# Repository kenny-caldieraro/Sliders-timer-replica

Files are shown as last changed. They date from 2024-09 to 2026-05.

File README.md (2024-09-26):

# Sliders Timer Replica

Welcome to the **Sliders Timer Replica** project! This project faithfully recreates the iconic "Timer" from the TV show _Sliders_, a device used for traveling between parallel universes. This replica is based on an Arduino microcontroller and includes electronic components, 3D design files, and the necessary schematics to build the casing and PCB.

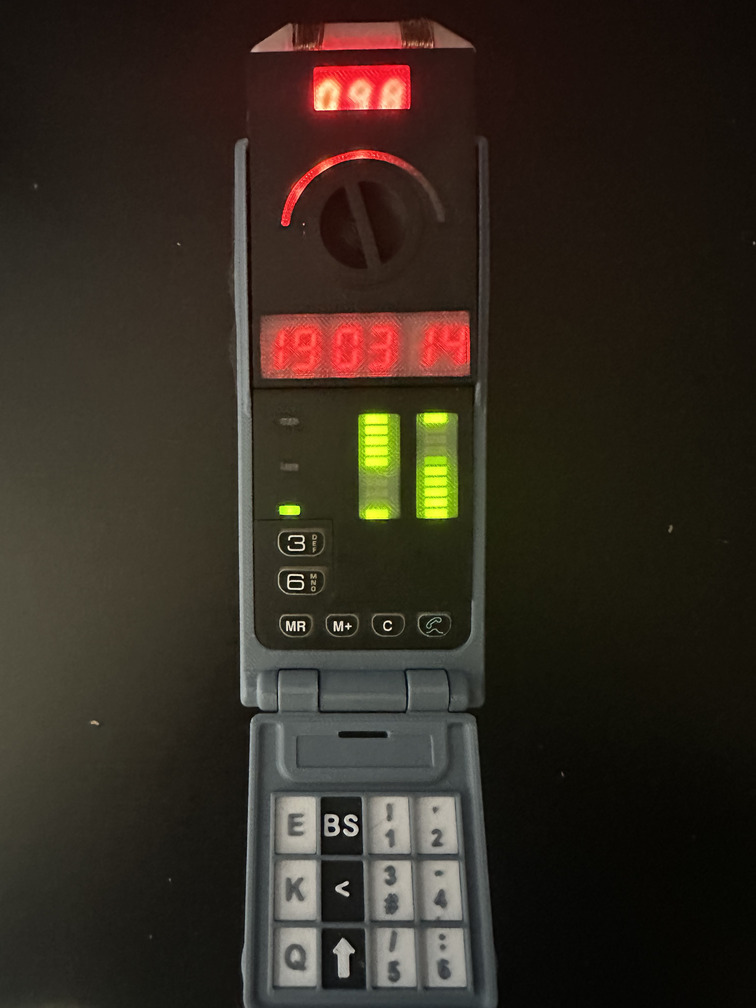
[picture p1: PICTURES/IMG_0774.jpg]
Sliders Timer Replica


## Project Content

- **Source Code**: Arduino sketch to control the Timer.
- **STL Files**: 3D models for printing the Timer casing.
- **Electronic Schematic**: Complete circuit diagrams for assembling the components.
- **Gerber Files**: Files for fabricating the PCB.
- **Photos**: Images of the completed Timer and various construction stages.

## Features

- **Visual and Functional Replica**: Design inspired by the _Sliders_ Timer, featuring an LED display to simulate the countdown.
- **Arduino Timer**: The Timer uses an Arduino microcontroller to handle the countdown and display functions.
- **3D Printable Casing**: All the necessary files to 3D print the casing are included in STL format.
- **DIY PCB**: The schematic and Gerber files allow you to build your own PCB for the Timer.
- **Easily Modifiable**: The code and schematics are provided for you to modify or improve as needed.

## Required Materials

To build this project, you will need the following:

- **Arduino Microcontroller** (e.g., Arduino Nano or similar)
- **7-segment LED display** or equivalent
- **Push buttons** for controls
- **Resistors, capacitors, etc.** (see the electronic schematic for a full list of components)
- **PCB** (Gerber files included for fabrication)
- **3D printed casing** (STL files provided)

### Component List

You can find the full list of required components in the [component list](./PARTS/ORIGINAL%20TIMERS%20PARTS.pdf) provided in this repository. This includes all resistors, capacitors, connectors, and other electronic parts required for the assembly.

## Installation Instructions

1. **Download the repository**:
   Clone this repository to your local machine:

   ```bash
   git clone https://github.com/kenny-caldieraro/Sliders-timer-replica.git

   ```

2. **3D Printing**:
   Print the casing parts using the provided STL files. Make sure you have a 3D printer and the appropriate filament.

3. **PCB Fabrication**:
   Use the Gerber files to order or fabricate the PCB.

4. **Electronic Assembly**:
   Assemble the electronic components as shown in the provided schematic and solder them onto the PCB.

5. **Upload the Code**:
   Upload the Arduino code to your microcontroller using the Arduino IDE:

   ```bash
   arduino-cli compile --upload
   ```

6. **Final Assembly**:
   Mount everything inside the 3D-printed casing and connect the components according to the diagrams.

## If you like it

[Support me on Buy Me a Coffee](https://buymeacoffee.com/kenny.caldieraro)

## Contributing

Contributions are welcome! If you'd like to improve this project, feel free to fork the repository and submit a pull request. Whether it's adding features, optimizing the code, or improving documentation, all help is appreciated.

## License

Sliders Timer Replica © 2021 by Kenny Caldieraro is licensed under CC BY-NC-SA 4.0 - see the LICENSE file for details.

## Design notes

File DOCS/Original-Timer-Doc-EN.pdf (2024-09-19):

Timer User Manual

Introduction

This device is an electronic apparatus based on Arduino that combines several functionalities such as display on 7-segment displays, light animations with NeoPixel LEDs, sound playback via a DFPlayer Mini MP3 module, and user interaction through multiple buttons.

Main Features

- Time Display: Shows days, hours, minutes, and seconds on 7-segment displays.
- LED Animations: Multiple integrated visual animations, including special effect sequences.
- Sound Management: Playback of sounds and tones via an integrated speaker.
- Battery Level Measurement: Displays the remaining battery percentage.
- Display of Remaining Time: Shows the remaining time in normal mode.
- Special Modes:
- Sleep and Wake Mode
- Test Mode
- Burnout Mode
- 29 Years Mode
- Parameter Control: Setting the timer (seconds, minutes, hours, days) via the buttons.

Description of Buttons

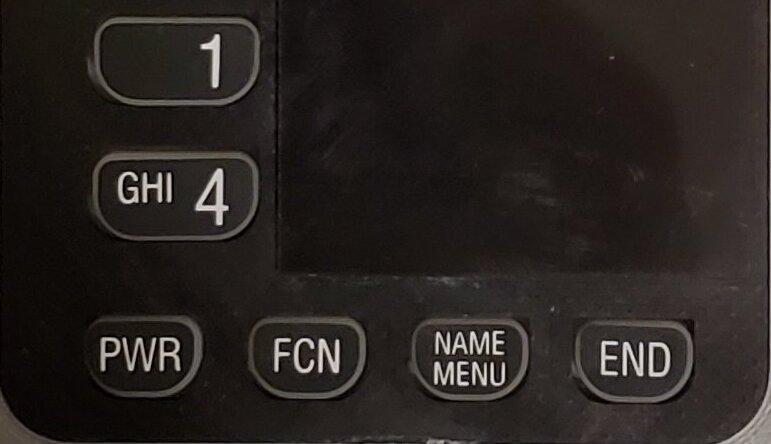
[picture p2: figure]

Button 1 (VORTEX) (BP_VORTEX - connected to A5)

- Press: Activates Burnout mode (if the timer is in normal mode), launching a special sequence of animations and sounds. No more control—the time is calculated randomly using a seed generated by the power adjustment potentiometer.

Button 4 (Sleep) (BP1 - connected to A4)

- Short Press: Puts the device into sleep mode. The displays and LEDs are turned off, and the buzzer is deactivated.
- Long Press: Wakes the device from sleep mode. The displays and LEDs are turned back on, and the buzzer is reactivated.
- Double Click: Directly accesses the timer setting menu.

Button PWR (Power) (BP2 - connected to A3)

- Short Press: Navigates to the next menu to set the timer (when the timer is not counting down).
- Long Press: Restarts the device.
- Double Click: Activates the timer with the current parameters.

Button FCN (DOWN) (BP_DOWN - connected to A2)

- In Setting Menus: Decreases the value of the current parameter (seconds, minutes, hours, days).
- Simultaneous Press with BP_UP: Activates test mode.
- During Timer Execution: Displays the battery level.

Button NAME MENU (UP) (BP_UP - connected to A1)

- In Setting Menus: Increases the value of the current parameter (seconds, minutes, hours, days).
- Simultaneous Press with BP_DOWN: Activates test mode.
- During Timer Execution: Displays the remaining time (only in normal mode).

Button END (START STOP) (BP_START - connected to A0)

- Simple Press: Starts the countdown after settings (SLIDE on the screen) in normal mode.
- During Timer Execution:
- Press: Activates or deactivates the buzzer.

Using the Device

Starting Up

- To turn on the device, double-click the Power button.

Sleep Mode

- To put the device into sleep mode, perform a short press on the Sleep button.
- The displays and LEDs turn off, and the buzzer is deactivated to save energy.

Exiting Sleep Mode

- To exit sleep mode, double-click the Sleep button.
- Note: Sleep mode does not stop the timer operation; it continues counting.

Setting the Timer

!!! IMPORTANT !!!

- The timer must be in a "waiting" state, indicated by the Arduino's status LED 13 blinking. By default, the timer is in this state at startup, but it may not always be the case. Simply click once on the Start/Stop button to set it.

Accessing the Setting Menu

- Press the POWER button to navigate through the timer setting menus.
- Each click advances you to the next menu.
- When the message “Slide” is displayed, you can click the START/STOP button to start the sequence. If an error message appears, the setting is incorrect.

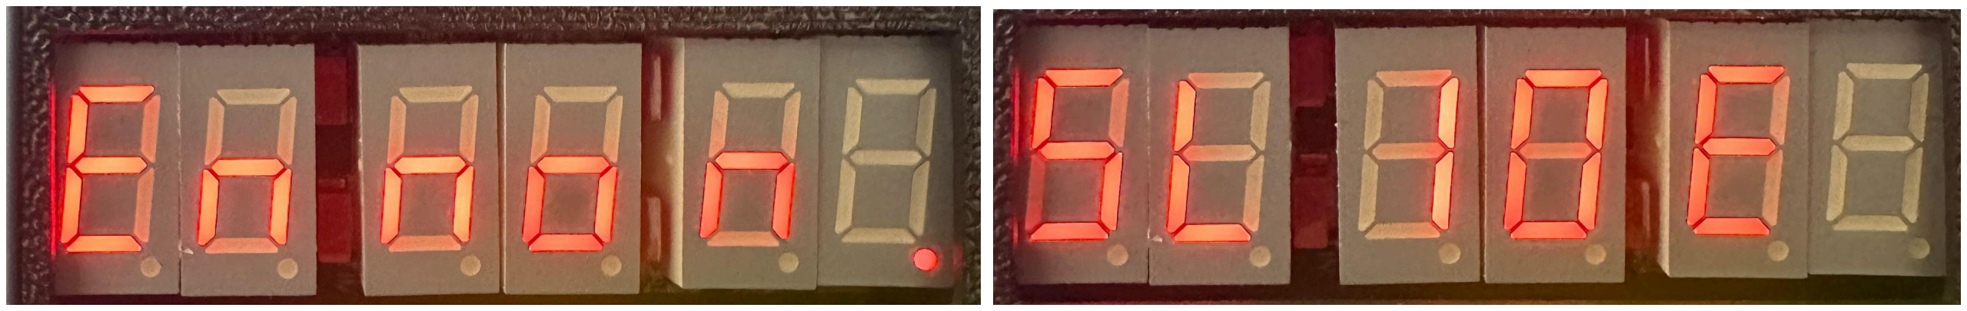
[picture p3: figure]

Selecting Parameters

- Menu 1: Setting seconds.
- Menu 2: Setting minutes.
- Menu 3: Setting hours.
- Menu 4: Setting days.
- Menu 5: Confirmation of parameters.
- Menu 6: Slide or Error message. If Slide, click the Start/Stop button to launch the sequence.

Adjusting Values

- Use the UP button to increase the value.
- Use the DOWN button to decrease the value.

Starting the Timer

- After setting the parameters, press the START/STOP button to launch the timer.

Timer Execution

While the timer is running:

- The device displays the elapsed time.
- Specific LED animations and sounds are played depending on the remaining time.
- Button Functions:
- DOWN: Displays the battery level.
- UP: Displays the remaining time.
- START/STOP (click): Activates or deactivates the buzzer.
- SLEEP (click/long press): Activates sleep mode or wakes up the timer.
- VORTEX: If clicked during the countdown, it activates the slide too early (Burnout mode), and the timer enters random mode.

Burnout Mode

- To activate Burnout mode, press the VORTEX button during timer execution.
- This mode launches a special sequence with unique animations and sounds.
- Initially, a 1 minute 30 seconds countdown is launched for demonstration. Then, depending on the position of the power potentiometer, a random time is calculated for each cycle.
- Important: In this mode, you must click the VORTEX button when there are between 0 and 2 seconds left to change the cycle; otherwise, the timer enters 29 Years Mode.
- Button Functions:
- DOWN: Displays the battery level.
- START/STOP (click): Activates or deactivates the buzzer.
- SLEEP (click/long press): Activates sleep mode or wakes up the timer.
- VORTEX: Activates the vortex when less than 2 seconds remain.

### 29 Years Mode

- You missed your slide in Burnout mode? Too bad—you are stuck here for 29 years. Hope this world suits you.

Displaying Battery Level

- At any time, you can display the battery level by pressing the DOWN button during timer execution.
- The device will display the remaining battery percentage on the 7-segment displays.

Test Mode

- To access test mode, press the UP and DOWN buttons simultaneously when the timer is in waiting mode.
- Test mode lights up all the LEDs and displays all the animations to verify the device's proper functioning.
- A continuous sound is emitted during the test.
- Test mode lasts 10 seconds, after which the device returns to the previous state.

Restarting the Device

- To restart the device, perform a long press on the POWER button.
- The device restarts, which can be useful in case of malfunction.

Visual and Sound Indications

- NeoPixel LEDs: Indicate the timer's power/generation of the random seed.
- 7-Segment Displays: Display time, animations, and special messages.
- Buzzer: Emits tones to signal specific events (startup, alerts, etc.).
- Speaker: Plays MP3s (vortex sound).

Safety and Precautions

- Ensure that the battery is correctly connected and charged to avoid any malfunction.
- Avoid pressing multiple buttons simultaneously unless otherwise indicated (as in test mode).
- Handle the device carefully to preserve sensitive electronic components.
- Do not connect the USB cable to the Arduino when the timer is powered by its battery. (Turn off the timer or disconnect the battery)

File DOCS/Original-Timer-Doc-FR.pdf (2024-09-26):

# Notice d'utilisation du minuteur

## Introduction

Cet appareil est un dispositif électronique basé sur Arduino qui combine plusieurs fonctionnalités telles que l'affichage sur afficheurs 7 segments, des animations lumineuses avec des LEDs NeoPixel, la lecture de sons via un module MP3 DFPlayer Mini, et l'interaction avec l'utilisateur grâce à plusieurs boutons.

## Caractéristiques Principales

- Affichage du temps : Affichage des jours, heures, minutes et secondes sur des afficheurs 7 segments.
- Animations LED : Plusieurs animations visuelles intégrées, y compris des séquences d'effets spéciaux.
- Gestion du son : Lecture de sons et tonalités via un haut-parleur intégré.
- Mesure du niveau de batterie : Affichage du pourcentage de la batterie restante.
- Affichage du temps restant : Affichage du temps restant en mode normal
- Modes Spéciaux :
- Mode Veille et Réveil
- Mode Test
- Mode Burnout
- Mode 29 years
- Contrôle des paramètres : Réglage du minuteur (secondes, minutes, heures, jours) via les boutons.

## Description des Boutons


Bouton 1 (VORTEX) (BP_VORTEX - connecté sur A5)

- Appui : Active le mode Burnout (si le minuteur est en mode normal), lançant une séquence spéciale d'animations et de sons. Plus de contrôle, le temps est calculé de manière aléatoire, en utilisant une graine générée par le potentiomètre de réglage de la puissance.

Bouton 4 (Sleep) (BP1 - connecté sur A4)

- Appui Court : Met l'appareil en mode veille. Les affichages et les LEDs sont éteints, et le buzzer est désactivé.
- Appui Long : Réveille l'appareil du mode veille. Les affichages et les LEDs sont rallumés, et le buzzer est réactivé.
- Double Clic : Accède directement au menu de réglage du minuteur.

Bouton PWR (Power) (BP2 - connecté sur A3)

- Appui Court : Navigue vers le menu suivant pour régler le minuteur. (Quand le minuteur n’est pas en train de décompter)
- Appui Long : Redémarre l'appareil.
- Double Clic : Active le minuteur avec les paramètres actuels.

Bouton FCN (DOWN) (BP_DOWN - connecté sur A2)

- Dans les menus de réglage : Diminue la valeur du paramètre en cours (secondes, minutes, heures, jours).
- Appui simultané avec BP_UP : Active le mode test.
- Pendant l'exécution du minuteur : Affiche le niveau de batterie.

Bouton NAME MENU (UP) (BP_UP - connecté sur A1)

- Dans les menus de réglage : Augmente la valeur du paramètre en cours (secondes, minutes, heures, jours).
- Appui simultané avec BP_DOWN : Active le mode test.
- Pendant l'exécution du minuteur : Affiche le temps restant (uniquement en mode normal).

Bouton END (START STOP) (BP_START - connecté sur A0)

- Appui simple : Démarre le compte à rebours après les réglages (SLIDE à l’écran) en mode normal.
- Pendant l'exécution du minuteur :
- Appui : Active ou désactive le buzzer.

## Utilisation de l'Appareil

Démarrage

- Pour allumer l'appareil, double-cliquez sur le bouton Power.

Mise en veille

- Pour mettre l'appareil en veille, effectuez un appui court sur le bouton Sleep.
- Les affichages et les LEDs s'éteignent, et le buzzer est désactivé pour économiser de l'énergie.

Sorti de veille

- Pour sortir de la veille double-cliquez sur le bouton Sleep.

Info : La mise en veille ne stoppe pas le fonctionnement du minuteur, il continue à compter.

Réglage du Minuteur
!!! IMPORTANT !!!

Le minuteur doit être en état “attente”, LED de statut 13 de l’Arduino qui clignote. Par défaut, le minuteur est dans cet état au démarrage, mais il peut arriver que ce ne soit pas le cas. Il suffit de cliquer une fois sur le bouton start/stop.

1. Accéder au Menu de Réglage :
- Appuyez sur le bouton POWER pour naviguer dans les menus de réglage du minuteur.
- Chaque clic vous fait changer de menu.
- Quand le message “Slide” est affiché, vous pouvez cliquer sur le bouton START/STOP pour démarrer la séquence. Si le message d'erreur s’affiche, le réglage n’est pas bon.

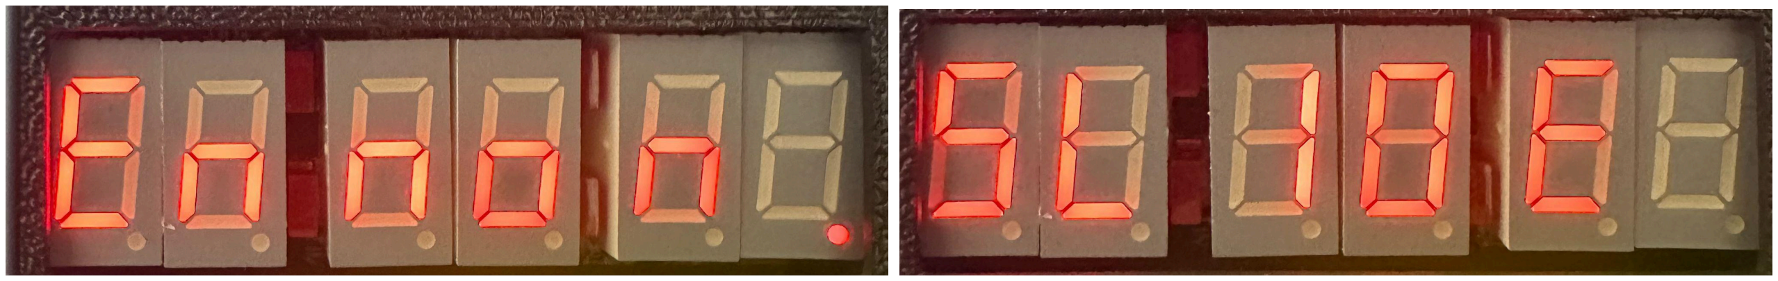
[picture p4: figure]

2. Sélection des Paramètres :
- Menu 1 : Réglage des secondes.
- Menu 2 : Réglage des minutes.
- Menu 3 : Réglage des heures.
- Menu 4 : Réglage des jours.
- Menu 5 : Confirmation des paramètres.

- Menu 6 : Message Slide ou Error => si Slide cliquez sur le bouton Start/Stop lance la séquence.
3. Ajustement des Valeurs :
- Utilisez le bouton UP pour augmenter la valeur.
- Utilisez le bouton DOWN pour diminuer la valeur.
4. Lancement du Minuteur :
- Après avoir réglé les paramètres, appuyez sur le bouton START/STOP pour lancer le minuteur.

Exécution du Minuteur

- Pendant que le minuteur est en cours :
- L'appareil affiche le temps passé.
- Des animations LED et des sons spécifiques sont joués en fonction du temps restant.
- Les boutons ont les fonctions suivantes :
■ DOWN : Affiche le niveau de batterie.
■ UP : Affiche le temps restant.
■ START/STOP (clic) : Active ou désactive le buzzer.
■ SLEEP : (clic / appui long) Active la veille ou sort de veille le minuteur. ■ VORTEX : Si on clique pendant le compte à rebours, cela active la glisse trop tôt (mode Burnout), le minuteur entre alors en mode aléatoire.

Mode Burnout

- Pour activer le mode Burnout, appuyez sur le bouton VORTEX pendant l'exécution du minuteur.
- Ce mode lance une séquence spéciale avec des animations et des sons uniques.
- Dans un premier temps, un compte à rebours de 1m30 est lancé pour la démonstration, puis, en fonction de la position du potentiomètre de puissance, un temps aléatoire est calculé à chaque cycle.
- Dans ce mode, il faut impérativement cliquer sur le bouton VORTEX quand il reste entre 0 et 2 secondes pour changer de cycle, sinon le minuteur entre en mode 29y.
- Les boutons ont les fonctions suivantes :
- DOWN : Affiche le niveau de batterie.
- START/STOP (clic) : Active ou désactive le buzzer.
- SLEEP : (clic / appui long) Active la veille ou sort de veille le minuteur.
- VORTEX :Active le vortex quand il reste moins de 2 secondes.

Mode 29 ans

- Vous avez raté votre glisse dans le mode Burnout ? Dommage, vous êtes bloqué ici pendant 29 ans. J'espère que ce monde vous convient.

Affichage du Niveau de Batterie

- À tout moment, vous pouvez afficher le niveau de batterie en appuyant sur le bouton DOWN pendant l'exécution du minuteur.
- L'appareil affichera le pourcentage de batterie restante sur les afficheurs 7 segments.

Mode Test

- Pour accéder au mode test, appuyez simultanément sur les boutons UP et DOWN quand le minuteur est en attente.
- Le mode test allume toutes les LEDs et affiche toutes les animations pour vérifier le bon fonctionnement de l'appareil.
- Un son continu est émis pendant le test.
- Le mode test dure 10 secondes, après quoi l'appareil revient à l'état précédent.

Redémarrage de l'Appareil

- Pour redémarrer l'appareil, effectuez un appui long sur le bouton POWER.
- L'appareil redémarre, ce qui peut être utile en cas de dysfonctionnement.

## Indications Visuelles et Sonores

- LEDs NeoPixel : Indiquent la puissance du minuteur / génération de la graine aléatoire.
- afficheurs 7 segments : Affichent le temps, les animations, et les messages spéciaux.
- Buzzer : Émet des tonalités pour signaler des événements spécifiques (démarrage, alertes, etc.).
- Haut parleur : Émet des MP3 (bruit du vortex).

## Sécurité et Précautions

- Assurez-vous que la batterie est correctement connectée et chargée pour éviter tout dysfonctionnement.
- Évitez d'appuyer sur plusieurs boutons simultanément, sauf indication contraire (comme pour le mode test).
- Manipulez l'appareil avec soin pour préserver les composants électroniques sensibles.
- Ne surtout pas brancher le câble USB à l’Arduino quand le minuteur est alimenté par sa batterie. (Éteindre le minuteur ou déconnecter la batterie)

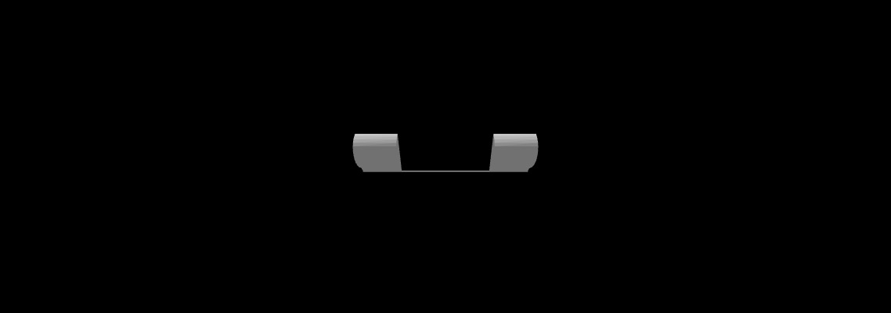
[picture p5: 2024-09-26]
STL/IMAGES/Flip_panels_nubs.STL.jpg

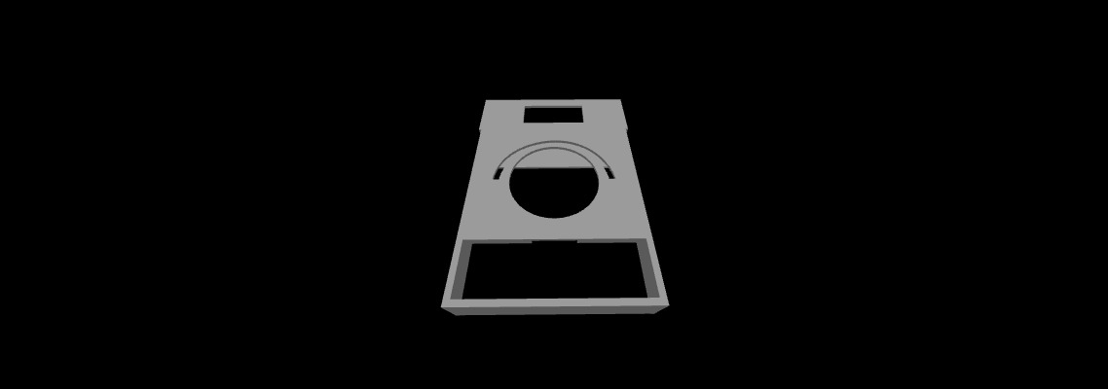
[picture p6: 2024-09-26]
STL/IMAGES/Top_face v1.jpg

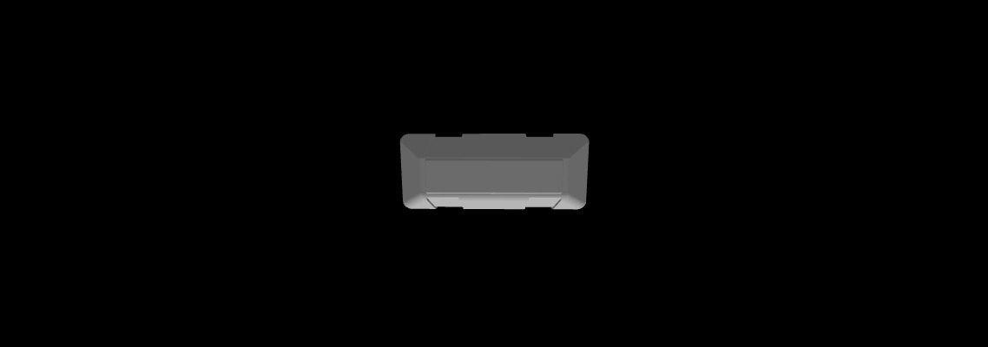
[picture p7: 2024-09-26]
STL/IMAGES/Crystal v3.jpg

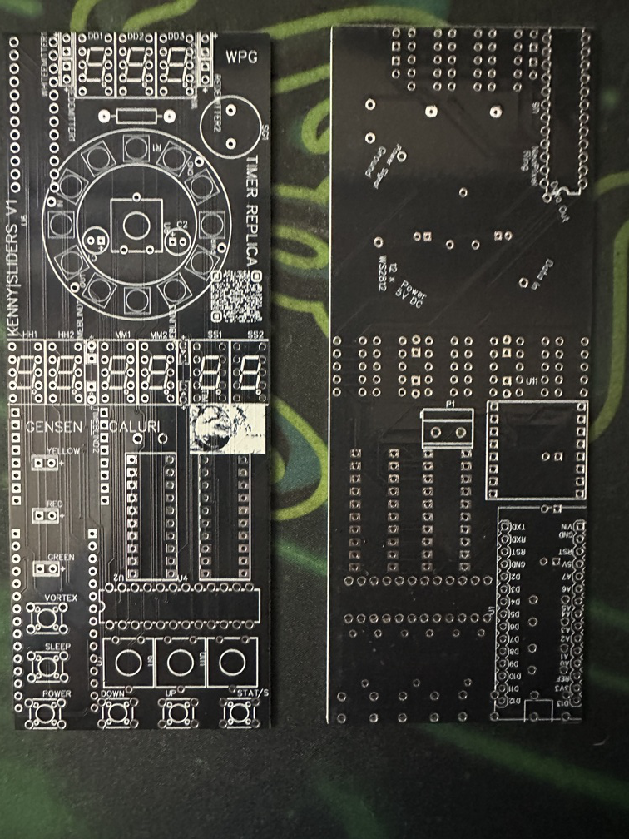
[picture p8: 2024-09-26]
PICTURES/PCB.jpeg

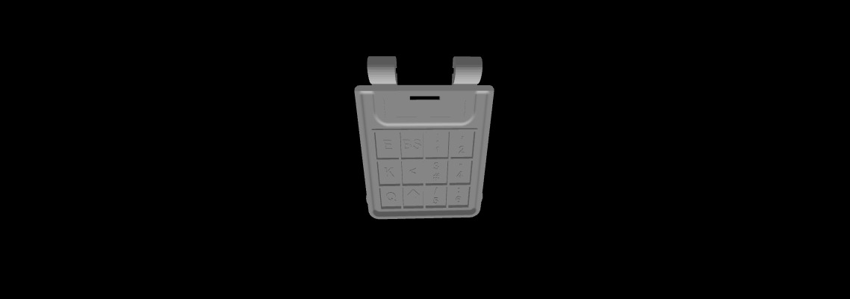
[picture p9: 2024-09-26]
STL/IMAGES/Flip_panel v7.jpg

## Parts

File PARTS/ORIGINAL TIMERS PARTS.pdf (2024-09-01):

Quantities | Name | Ref
2 | Led controller | MAX7219ENG+
6 | Button | OMRON B3F-1022
6 | 7 Segments HHMMSS | KINGBRIGHT SC36-11EWA
3 | 7 Segments DDD | BROADCOM HDSP-7513
2 | Bargraphe | KINGBRIGHT DC-10GWA
1 | Buzzer | KINGSTATE KXG1205C
4 | Blink LED | KINGBRIGHT L-144IDT
1 | Red LED | KINGBRIGHT L-113IDT
1 | Green LED | KINGBRIGHT L-103GDT
1 | Yellow LED | KINGBRIGHT L-113YDT
1 | Resistor | MCRE000037 1K 125mW
1 | Resistor | MCRE000067 330k 125mW
2 | Condensator | MCNP63V474M5X11 63v 0.47
4 | Potentiometer | 3386F-1-103TLF 10K
2 | White LED Emitter | PSG91880
2 | Red LED Emitter | 703-0100
1 | 12 LEDS | NEO Pixel led ring
1 | Arduino NANO | Arduino NANO
1 | MP3 SOUND | 2 pièces Module de Lecteur MP3 Open Source Mini capteur de Lecteur MP3 avec boîtier métallique Haut - Parleur Rond 2W 8ohm (Module 2 pièces et Haut - Parleur 4 pièces) Compatible arduino
1 | Alimentation board | Aideepen 6pcs TC4056 Type-C USB-C Input Interface USB 5V 1A 18650 LiIon Lithium Charging Board Charger Module with Dual Protection Functions (en Anglais)
1 | Battery 1s | EEMB 3.7V Lipo Battery 1800mAh Rechargeable Lithium Polymer ION Battery Pack Li Polymer Battery 3.7v Packs (1 Count, 953450
1 | Connectors | LinsyRC 10 Paires Adaptateur Connecteur Mâle et Femelle 2-Broches JST 1S 2.0 Pitch Câble pour Batterie 1S Lipo Drone de Charge Syma X5C X5SW SNAPTAIN S5C

Link
https://fr.farnell.com/analog-devices/max7219eng/driver-afficheur-led-40-a-85-c/dp/2519194

https://fr.farnell.com/omron/b3f-1022/commutateur-6x6-spno-5mm-plunger/dp/1829495

https://fr.farnell.com/kingbright/sc36-11ewa/afficheur-led-0-36-rouge-cathode/dp/2314224

https://fr.farnell.com/broadcom-limited/hdsp-7513/afficheur-a-leds-7-62mm-he-rouge/dp/1003281

https://fr.farnell.com/kingbright/dc-10gwa/bargraphe-reseau-de-10-segments/dp/2290324

https://fr.farnell.com/kingstate/kxg1205c/buzzer-magnetique-broche-85db/dp/2215080

https://fr.farnell.com/kingbright/l-144idt/led-rectangulaire-rouge-he/dp/1142602

https://fr.farnell.com/kingbright/l-113idt/led-2x5mm-superail-railouge-4mcd/dp/2314275

https://fr.farnell.com/kingbright/l-103gdt/led-2x5mm-vert-5mcd-568nm/dp/2314269

https://fr.farnell.com/kingbright/l-113ydt/led-2x5mm-jaune-4mcd-588nm/dp/2314278

https://fr.farnell.com/multicomp/mcre000037/resistance-couche-carbon-1k-0/dp/1700237

https://fr.farnell.com/multicomp/mcre000067/resistance-couche-carbon-125mw/dp/1700270

https://fr.farnell.com/multicomp/mcnp63v474m5x11/condensateur-0-47-f-63v-20/dp/1236676

https://fr.farnell.com/bourns/3386f-1-103tlf/potentiometre-trimmer-10k-10-1/dp/9354565

https://fr.farnell.com/pro-signal/psg91880/led-5mm-cool-white-water-clear/dp/4161123

https://fr.farnell.com/multicomp/703-0100/led-rouge-5mm-standard/dp/2112111

https://shorturl.at/3z6kg

https://shorturl.at/d0E4x

https://shorturl.at/T3ka4

https://www.amazon.fr/dp/B095VQRW73?ref=ppx_yo2ov_dt_b_fed_asin_title

https://www.amazon.fr/dp/B09TJDNN66?ref=ppx_yo2ov_dt_b_fed_asin_title

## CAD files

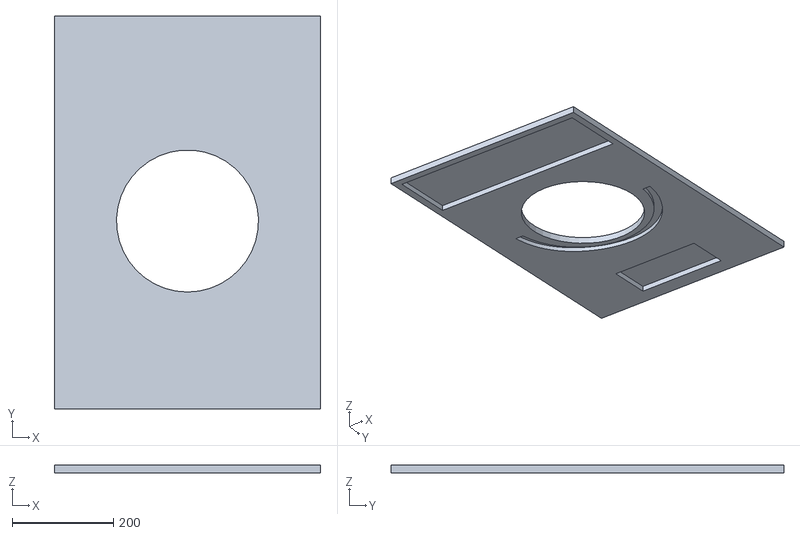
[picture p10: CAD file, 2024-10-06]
STL/FILES/Cover_Top_face v14.stl
525.0 x 775.0 x 15.0

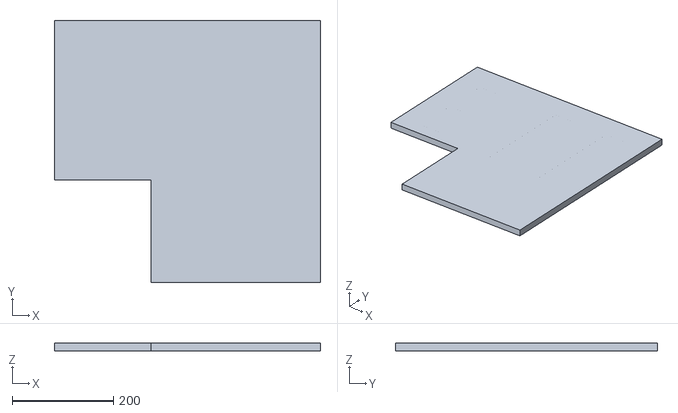
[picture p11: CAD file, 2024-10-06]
STL/FILES/Cover_Button_plate v12.stl
525.0 x 516.8 x 15.0

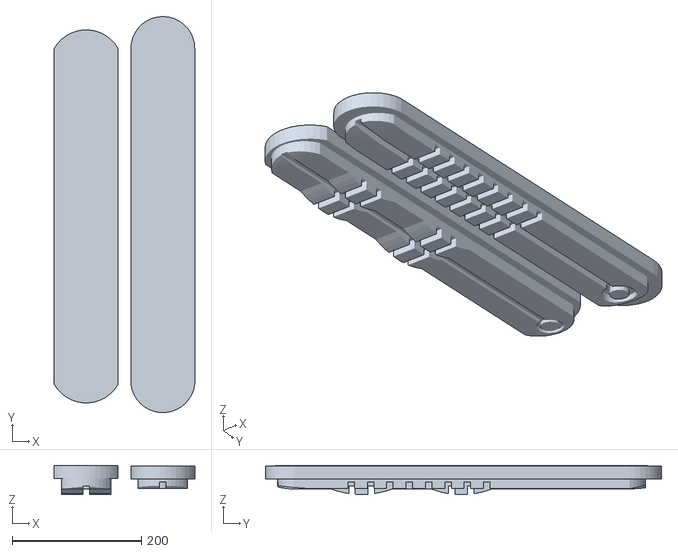
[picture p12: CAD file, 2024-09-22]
STL/FILES/Aside_parts v8.stl
217.7 x 613.1 x 45.4

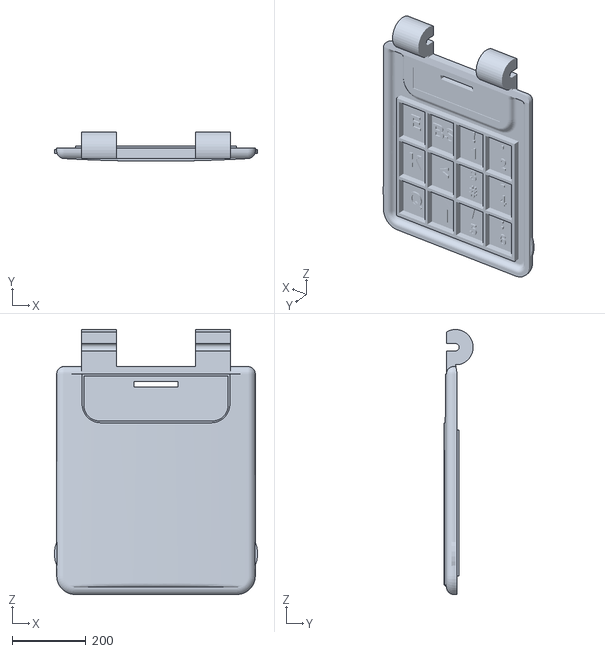
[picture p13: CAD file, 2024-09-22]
STL/FILES/Flip_panel v7.stl
549.6 x 79.5 x 717.1

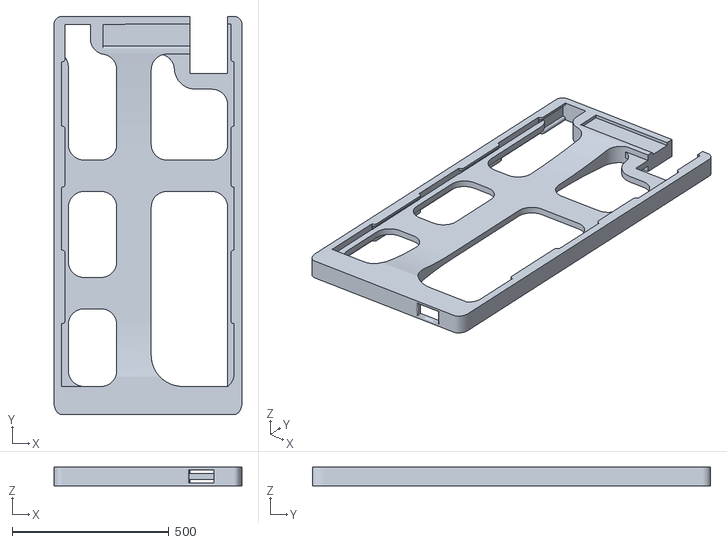
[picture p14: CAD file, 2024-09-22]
STL/FILES/Spacer_battery v9.stl
599.4 x 1270.0 x 60.0

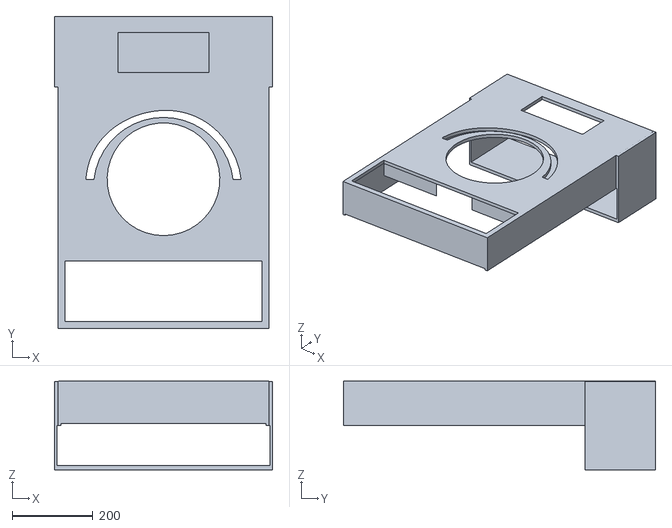
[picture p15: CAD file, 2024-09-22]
STL/FILES/Top_face v1.stl
541.8 x 775.0 x 220.2

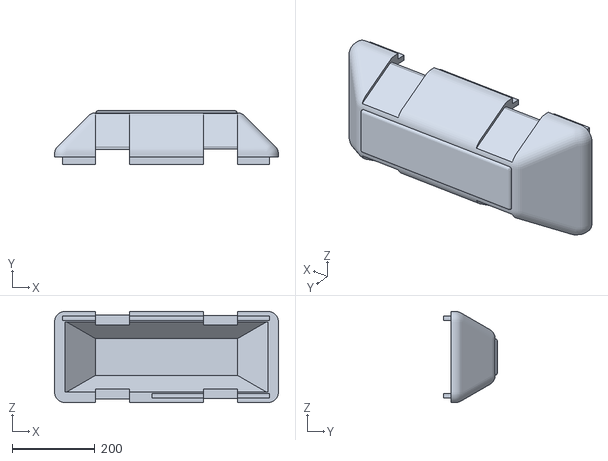
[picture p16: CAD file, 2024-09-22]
STL/FILES/Crystal v3.stl
540.8 x 129.4 x 220.2

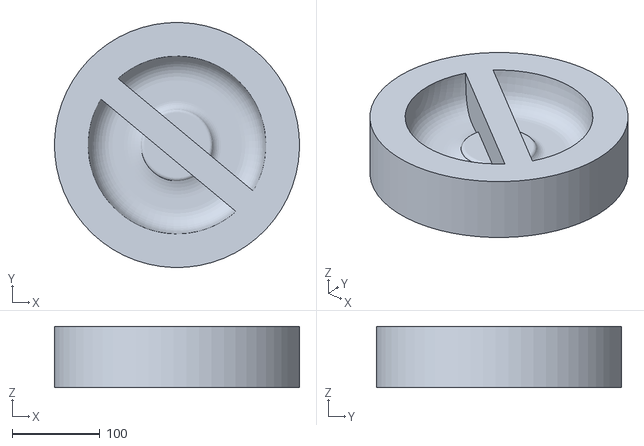
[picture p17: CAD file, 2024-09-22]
STL/FILES/Potentiometer v2.stl
279.3 x 279.3 x 69.9

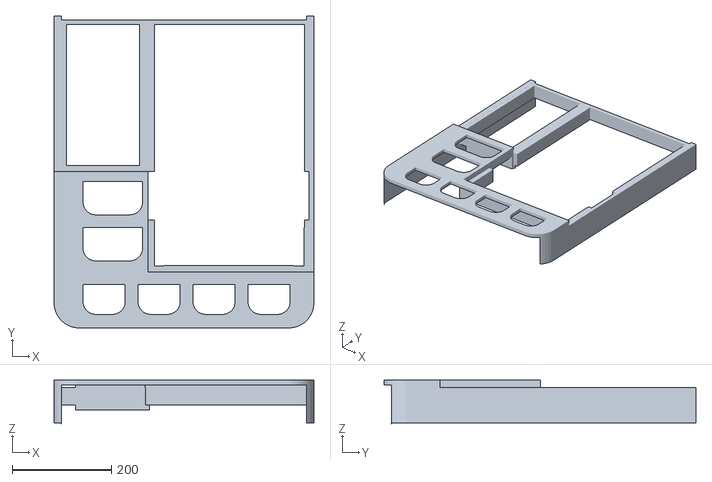
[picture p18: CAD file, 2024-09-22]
STL/FILES/Button_plate v1.stl
525.0 x 629.9 x 88.8

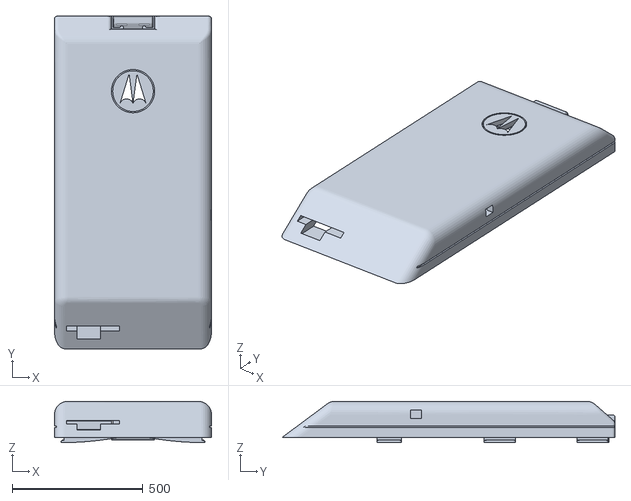
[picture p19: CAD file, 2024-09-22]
STL/FILES/Battery_box v9.stl
599.4 x 1270.5 x 157.5

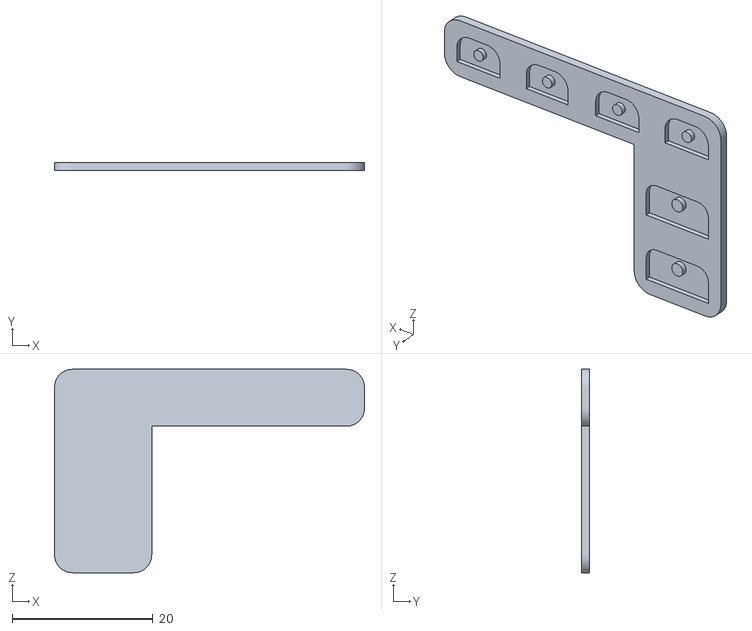
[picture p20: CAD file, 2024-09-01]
STL/FILES/Buttons_pad v2.stl
44.0 x 1.19 x 28.9

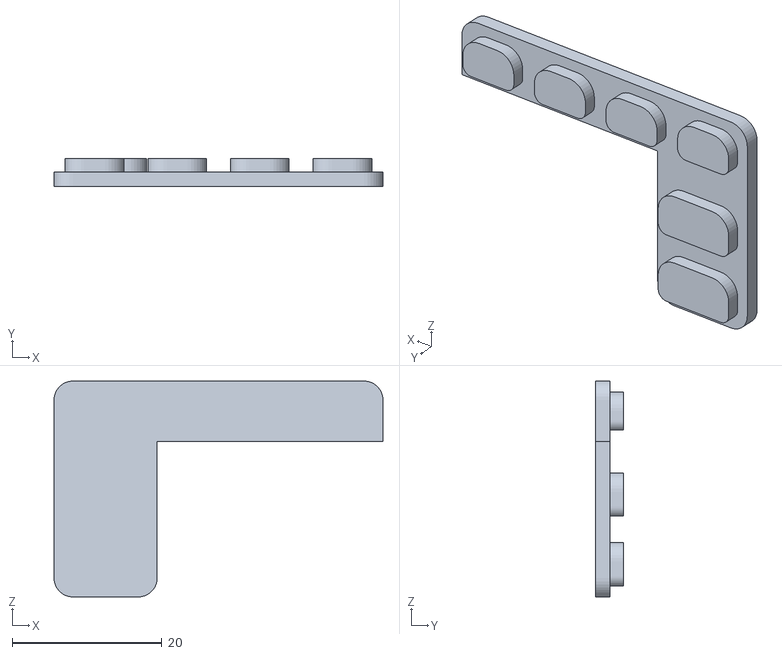
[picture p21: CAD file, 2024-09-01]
STL/FILES/Buttons.stl
44.0 x 3.68 x 28.9

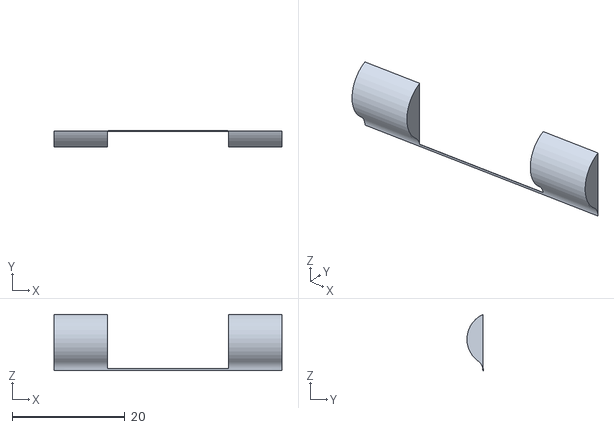
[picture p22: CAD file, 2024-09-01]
STL/FILES/Flip_panels_nubs.STL
40.4 x 2.86 x 9.95

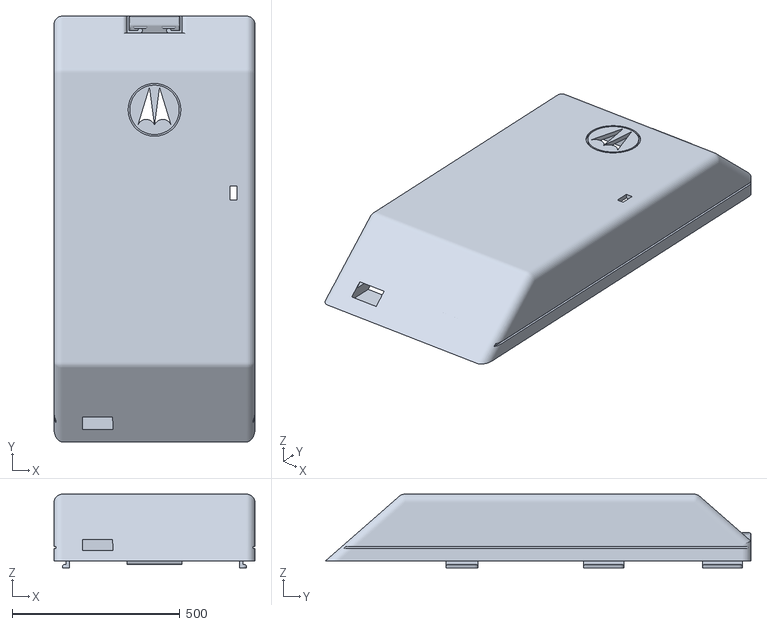
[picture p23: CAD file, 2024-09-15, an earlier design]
STL/FILES/Battery_box v1.stl
599.4 x 1270.0 x 220.0

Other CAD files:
STL/FILES/Font_face v1.stl

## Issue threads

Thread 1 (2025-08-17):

Download STLs

ondutyapp, 2025-08-17:
The downloads initially fail but when re attempted they do download but the files seem to be corrupted. Can you assist?

kenny-caldieraro, 2025-08-28:
I’m not the one managing the .zip files; they are generated directly by GitHub. The files are not corrupted—I downloaded them about 10 minutes ago to test. You still have the option to run a git clone of the repository.

Closed 2025-08-28.

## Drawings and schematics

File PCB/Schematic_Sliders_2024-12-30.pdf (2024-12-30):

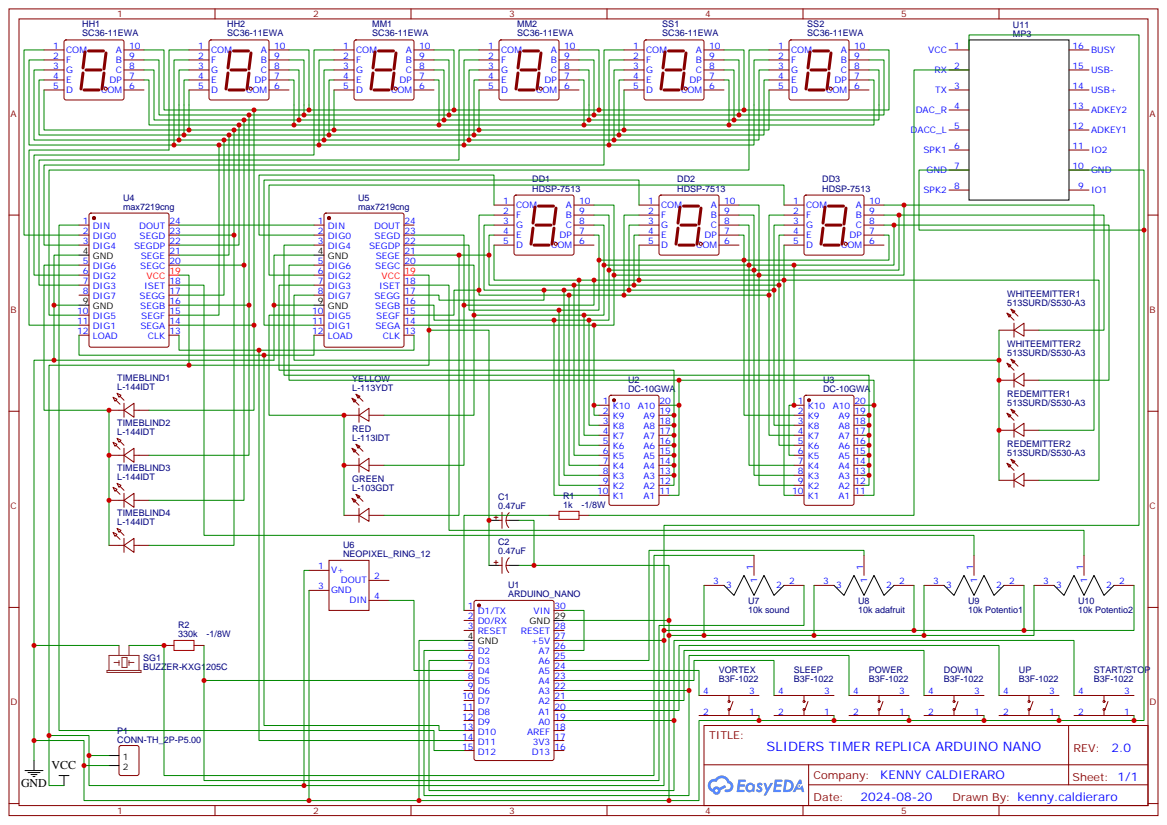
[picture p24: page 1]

Drawn By: kenny.caldieraro

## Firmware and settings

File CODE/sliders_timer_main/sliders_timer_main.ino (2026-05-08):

#include "LedControl.h"
#include "OneButton.h"
#include "Adafruit_NeoPixel.h"
#include "DFPlayer_Mini_Mp3.h"
#include <avr/wdt.h>
#include <EEPROM.h>

#define BP_START A0
#define BP_UP A1
#define BP_DOWN A2
#define ADAFRUITPIN 4
#define BP_VORTEX A5
#define BATTERYPIN A7

// --- Parametres audio / animation ---
const uint8_t  DFPLAYER_VOLUME       = 28;     // 0-30
const uint16_t START_INTRO_DELAY_MS  = 2500;   // ecrans noirs au demarrage
const uint16_t START_OUTRO_DELAY_MS  = 2500;   // attente apres l'animation pour synchro fin du clip
const uint16_t VORTEX_MP3_DURATION_MS = 8000;  // duree du 0001.mp3 (vortex)
const uint16_t COUNTDOWN_BIP_FREQ    = 3820;   // freq bip countdown (mesuree sur clip)
const uint16_t START_LOCK_TONE_FREQ  = 3000;   // freq bip de fin (3 sec / 1.5 sec)

// --- Parametres timer ---
const unsigned long SECONDS_IN_DAY    = 86400UL;
const unsigned long SECONDS_IN_HOUR   = 3600UL;
const unsigned long SECONDS_IN_MINUTE = 60UL;
const unsigned long VORTEX_RANDOM_MAX = 16756131UL;  // ~193 jours

// --- EEPROM ---
const int EEPROM_MAGIC_ADDR = 0;
const uint8_t EEPROM_MAGIC_VALUE = 0xA5;
const int EEPROM_TOTALSECTIME_SLIDE_ADDR = 1;

struct LED {
  int pinState;
  unsigned long previousMillis;
  unsigned long interval;
  int matrixIndex;
  bool isColon;
  int colIndex;
  bool isArduinoLED;
  int arduinoPin;
};

struct Bargraphe {
  const uint64_t *images;
  int length;
  int index;
  int delayTime;
};

// Format generique pour les animations 7-segments stockees en PROGMEM:
// 6 bytes matrix 0 (rows 0-5) + 5 bytes matrix 1 (rows 0-4)
// + tone optionnel (freq=0 -> pas de tone) + delay apres affichage.
struct AnimFrame {
  uint8_t r0[6];
  uint8_t r1[5];
  uint16_t tone_freq;  // 0 = pas de tone
  uint8_t tone_dur;    // duree du tone en ms
  uint8_t delay_ms;    // delay apres affichage
};

// Format pour genserSequence: pattern affiche-bip-attend-clear-attend.
struct GenserFrame {
  uint8_t r0[6];
  uint8_t r1[5];
  uint16_t hold_ms;        // delay avec frame affichee + tone
  uint8_t clear_pause_ms;  // delay apres clear
};

// Prototypes (necessaire car les arguments par defaut ne sont pas captures
// dans la forward declaration auto-generee par Arduino).
void reveille(bool fadeIn = true);

Adafruit_NeoPixel strip = Adafruit_NeoPixel(7, ADAFRUITPIN, NEO_GRB + NEO_KHZ800);
int prevVal = 0;

// Lissage de la valeur du potentiomètre
const int numReadings = 10;
int readings[numReadings];
int readIndex = 0;
int total = 0;
int average = 0;

uint32_t Red = strip.Color(255, 0, 0);
uint32_t Off = strip.Color(0, 0, 0);

LedControl lc = LedControl(12, 11, 10, 2);

const int pot1 = A6;
const int speaker = 5;
const int etatarduino = 13;

OneButton button1(A4, true);
OneButton button2(A3, true);

volatile byte running = false;

unsigned long totalsectime_slide = 0;
unsigned long totalsectime = 0;

bool BP_START_STATUS = false;
bool OLD_BP_START_STATUS = false;
unsigned long lastDebounceTime = 0;
unsigned long debounceDelay = 50;

bool BP_VORTEX_STATUS = false;
bool OLD_BP_VORTEX_STATUS = false;
unsigned long lastDebounceTime1 = 0;
unsigned long debounceDelay1 = 50;

bool BP_POWER_STATUS = false;

const float TensionMin = 3.2;
const float TensionMax = 4.2;

bool firstStartup = true;     // flag du 1er passage du double-click power (init musique + screens)
bool wrapPlayedAt10s = false; // flag pour rejouer displayWrap une seule fois quand burnout=10s
int menu = 0;
int buzzerState = 1;

void setup() {
  Serial.begin(9600);
  mp3_set_serial(Serial);
  mp3_set_volume(28);
  mp3_set_EQ(0);

  button1.attachClick(click1);
  button1.attachDoubleClick(doubleclick1);
  button1.attachDuringLongPress(longPress1);

  button2.attachClick(click2);
  button2.attachDoubleClick(doubleclick2);
  button2.attachDuringLongPress(longPress2);

  int devices = lc.getDeviceCount();
  for (int address = 0; address < devices; address++) {
    lc.shutdown(address, false);
    lc.setIntensity(address, 15);
    lc.clearDisplay(address);
    lc.setScanLimit(address, 7);
  }

  for (int i = 0; i < numReadings; i++) {
    readings[i] = 0;
  }

  pinMode(speaker, OUTPUT);
  pinMode(etatarduino, OUTPUT);
  pinMode(pot1, INPUT);
  randomSeed(analogRead(pot1));

  pinMode(BP_UP, INPUT_PULLUP);
  pinMode(BP_DOWN, INPUT_PULLUP);
  pinMode(BP_START, INPUT_PULLUP);
  pinMode(BP_VORTEX, INPUT_PULLUP);
  attachInterrupt(1, buttonStart, FALLING);

  strip.begin();
  strip.show();

  // Restaure le dernier temps lock depuis EEPROM (si valide).
  // On ne restaure QUE totalsectime_slide; totalsectime reste a 0 sinon
  // le compteur considere le countdown comme deja termine.
  if (EEPROM.read(EEPROM_MAGIC_ADDR) == EEPROM_MAGIC_VALUE) {
    EEPROM.get(EEPROM_TOTALSECTIME_SLIDE_ADDR, totalsectime_slide);
  }

  // Disable watchdog (au cas ou on viendrait d'un reboot watchdog)
  wdt_disable();
}

LED redLED = { HIGH, 0, 600, 4, false, 0, false, -1 };
LED yellowLED = { HIGH, 0, 250, 3, false, 0, false, -1 };
LED greenLED = { HIGH, 0, 200, 5, false, 0, false, -1 };
LED colonLED = { HIGH, 0, 150, 0, true, 6, false, -1 };
LED etatArduinoLED = { HIGH, 0, 100, -1, false, 0, true, etatarduino };

void blinkLEDUnified(LED &led) {
  unsigned long currentMillis = millis();

  if (currentMillis - led.previousMillis >= led.interval) {
    led.previousMillis = currentMillis;

    led.pinState = !led.pinState;

    if (led.isColon) {
      lc.setLed(0, led.colIndex, 1, led.pinState);
      lc.setLed(0, led.colIndex, 2, led.pinState);
      lc.setLed(0, led.colIndex, 3, led.pinState);
      lc.setLed(0, led.colIndex, 4, led.pinState);
    } else if (!led.isColon && !led.isArduinoLED) {
      lc.setLed(1, 5, led.matrixIndex, led.pinState);
    } else if (led.isArduinoLED) {
      digitalWrite(led.arduinoPin, led.pinState);
    }
  }
}

void ecranBlinkUnified(bool allSegments, int bloc = 0, int ecran = 0) {
  static int stateecran = 0;
  static unsigned int ecrantime = 250;
  static unsigned int ecraninterval = 500;
  static unsigned long lasttimeecran = 0;
  unsigned long mecran = millis();

  if (stateecran == 0) {
    if (mecran >= lasttimeecran + ecraninterval) {
      stateecran = 1;
      showTime();
      lasttimeecran = mecran;
    }
    return;
  }
  if (stateecran == 1) {
    if (mecran >= lasttimeecran + ecrantime) {
      if (allSegments) {
        for (int i = 0; i < 8; i++) {
          lc.setRow(0, i, false);
          lc.setRow(1, i, false);
        }
      } else {
        lc.setRow(bloc, ecran, false);
      }

      stateecran = 0;
      ecrantime = 250;
    }
    return;
  }
}

void customTone(int frequency, int duration = 0) {
  if (buzzerState == 1) {
    if (duration > 0) {
      tone(speaker, frequency, duration);
    } else {
      tone(speaker, frequency);
    }
  } else {
    noTone(speaker);
  }
}

// Attente non-bloquante pour les boutons: equivalent a delay(ms) mais en
// continuant a appeler button.tick() pour ne pas perdre les clics utilisateur.
void waitMs(unsigned long ms) {
  unsigned long start = millis();
  while (millis() - start < ms) {
    button1.tick();
    button2.tick();
  }
}

void updatespeaker_pattern(int interval, int numBips, int pause) {
  static int state = 0;
  static unsigned int beeptime = 50;
  static unsigned long lasttimeon = 0;
  static unsigned int bipCount = 0;
  static int lastInterval = -1;
  static int lastNumBips = -1;
  static int lastPause = -1;
  unsigned long m = millis();

  // Reset l'etat si le pattern change (sinon le bipCount/state d'un pattern
  // precedent peut donner un rythme bizarre quand on saute des paliers).
  if (interval != lastInterval || numBips != lastNumBips || pause != lastPause) {
    state = 0;
    bipCount = 0;
    lasttimeon = m;
    lastInterval = interval;
    lastNumBips = numBips;
    lastPause = pause;
  }

  if (bipCount >= numBips) {
    if (m >= lasttimeon + pause) {
      bipCount = 0;
      state = 0;
    }
    return;
  }

  if (state == 0) {
    if (m >= lasttimeon + interval) {
      state = 1;
      customTone(COUNTDOWN_BIP_FREQ);
      lasttimeon = m;
    }
    return;
  }

  if (state == 1) {
    if (m >= lasttimeon + beeptime) {
      noTone(speaker);
      state = 0;
      lasttimeon = m;
      bipCount++;
    }
    return;
  }
}

// Texte de version qui defile sur les ecrans 7-segments au demarrage (1er
// double-click power). Padding gauche/droite pour entree/sortie smooth.
const char VERSION_TEXT[] PROGMEM = "         sliders timer replica by kenny v1.2         ";

// Conversion d'un caractere ASCII en bitmap 7-segments (A-G, bit 6 = top).
byte charToSeg(char c) {
  switch (c) {
    case ' ': return 0x00;
    case '0': return 0x7E;
    case '1': return 0x30;
    case '2': return 0x6D;
    case '3': return 0x79;
    case '4': return 0x33;
    case '5': return 0x5B;
    case '6': return 0x5F;
    case '7': return 0x70;
    case '8': return 0x7F;
    case '9': return 0x7B;
    case 'a': return 0x77;
    case 'b': return 0x1F;
    case 'c': return 0x0D;
    case 'd': return 0x3D;
    case 'e': return 0x4F;
    case 'f': return 0x47;
    case 'h': return 0x17;
    case 'i': return 0x10;
    case 'k': return 0x37;
    case 'l': return 0x0E;
    case 'm': return 0x15;  // approximation (n minuscule)
    case 'n': return 0x15;
    case 'o': return 0x1D;
    case 'p': return 0x67;
    case 'r': return 0x05;
    case 's': return 0x5B;
    case 't': return 0x0F;
    case 'u': return 0x1C;
    case 'v': return 0x1C;  // approximation (u)
    case 'y': return 0x3B;
    case '.': return 0x80;  // decimal point seul
    case '-': return 0x01;
    default:  return 0x00;
  }
}

// Defile le texte VERSION_TEXT sur les 9 ecrans (6 sur matrix 0 + 3 sur matrix 1).
void scrollVersion() {
  int len = strlen_P(VERSION_TEXT);
  for (int pos = 0; pos <= len - 9; pos++) {
    for (int i = 0; i < 6; i++) {
      char c = pgm_read_byte(&VERSION_TEXT[pos + i]);
      lc.setRow(0, i, charToSeg(c));
    }
    for (int i = 0; i < 3; i++) {
      char c = pgm_read_byte(&VERSION_TEXT[pos + 6 + i]);
      lc.setRow(1, i, charToSeg(c));
    }
    delay(150);
  }
  lc.clearDisplay(0);
  lc.clearDisplay(1);
}

void startMusique() {
  // Joue le clip d'activation Sliders Timer via le DFPlayer Mini.
  // Fichier 0003.mp3 sur la carte SD.
  mp3_play_physical(3);  // 0003.mp3 = clip d'activation Sliders Timer
  waitMs(START_INTRO_DELAY_MS);  // ecrans noirs au debut du clip (effet d'intro)
}

// Frames de genserSequence: 8 ecrans textes/scrambled successifs avec bip.
// r1 dans l'ordre [0,1,2,3,4]. Tous les bips sont 5500 Hz / 50 ms.
const GenserFrame GENSER_FRAMES[] PROGMEM = {
  // GEnSEr
  {{0x5E, 0x4F, 0x15, 0x5B, 0x4F, 0x05}, {0x49, 0x03, 0x5E, 0x88, 0x88}, 400, 40},
  // random 1
  {{0x49, 0x15, 0x23, 0x03, 0x54, 0x43}, {0x05, 0x40, 0x40, 0xAA, 0x8A}, 200, 40},
  // CAluri
  {{0x4E, 0x77, 0x30, 0x1C, 0x05, 0x10}, {0x43, 0x08, 0x54, 0x82, 0x0A}, 200, 40},
  // 4th
  {{0x23, 0x03, 0x54, 0x43, 0x13, 0x19}, {0x30, 0x41, 0x4E, 0x89, 0x4A}, 200, 40},
  // Second CAluri
  {{0x4E, 0x77, 0x30, 0x1C, 0x05, 0x10}, {0x2A, 0x1A, 0x1A, 0x29, 0x0A}, 200, 40},
  // 6th
  {{0x2A, 0x03, 0x1A, 0x48, 0x41, 0x49}, {0x19, 0x09, 0x13, 0x29, 0x0A}, 200, 40},
  // 7th
  {{0x13, 0x19, 0x22, 0x18, 0x41, 0x25}, {0x33, 0x37, 0x89, 0x95, 0x24}, 200, 40},
  // KEnnY
  {{0x37, 0x4F, 0x15, 0x15, 0x33, 0x01}, {0x21, 0x11, 0x41, 0x89, 0x89}, 350, 75}
};

void genserSequence() {
  GenserFrame f;
  const uint8_t N = sizeof(GENSER_FRAMES) / sizeof(GENSER_FRAMES[0]);
  for (uint8_t i = 0; i < N; i++) {
    memcpy_P(&f, &GENSER_FRAMES[i], sizeof(GenserFrame));
    for (uint8_t r = 0; r < 6; r++) lc.setRow(0, r, f.r0[r]);
    for (uint8_t r = 0; r < 5; r++) lc.setRow(1, r, f.r1[r]);
    customTone(5500, 50);
    delay(f.hold_ms);
    lc.clearDisplay(0);
    lc.clearDisplay(1);
    noTone(speaker);
    delay(f.clear_pause_ms);
  }
}

void renderAnimFrame(const AnimFrame *frame_pgm) {
  AnimFrame f;
  memcpy_P(&f, frame_pgm, sizeof(AnimFrame));
  if (f.tone_freq) customTone(f.tone_freq, f.tone_dur);
  for (uint8_t r = 0; r < 6; r++) lc.setRow(0, r, f.r0[r]);
  for (uint8_t r = 0; r < 5; r++) lc.setRow(1, r, f.r1[r]);
  if (f.delay_ms) delay(f.delay_ms);
}

const AnimFrame DISPLAY_FADE_FRAMES[] PROGMEM = {
  {{0x78, 0x7E, 0x7E, 0x7E, 0x7E, 0x1E}, {0x7F, 0x7F, 0x7F, 0xFF, 0xFF}, 0, 0, 30},
  {{0x30, 0x7E, 0x7E, 0x7E, 0x80, 0x06}, {0x3F, 0x3F, 0x3F, 0xEF, 0xEF}, 0, 0, 30},
  {{0x00, 0x7E, 0x7E, 0x7E, 0x7E, 0x00}, {0x2F, 0x2F, 0x2F, 0xE7, 0xE7}, 0, 0, 30},
  {{0x00, 0x78, 0x7E, 0x7E, 0x40, 0x00}, {0x2B, 0x2B, 0x2B, 0xC7, 0xC7}, 0, 0, 30},
  {{0x00, 0x30, 0x7E, 0x7E, 0x06, 0x00}, {0x0B, 0x0B, 0x0B, 0xC3, 0xC3}, 0, 0, 30},
  {{0x00, 0x00, 0x7E, 0x7E, 0x00, 0x00}, {0x09, 0x09, 0x09, 0x83, 0x83}, 0, 0, 55},
  {{0x00, 0x00, 0x78, 0x40, 0x00, 0x00}, {0x01, 0x01, 0x01, 0x81, 0x81}, 0, 0, 30},
  {{0x00, 0x00, 0x30, 0x06, 0x00, 0x00}, {0x00, 0x00, 0x00, 0x01, 0x01}, 0, 0, 30},
  {{0x00, 0x00, 0x00, 0x00, 0x00, 0x00}, {0x00, 0x00, 0x00, 0x00, 0x00}, 0, 0,  0}
};

void displayFade() {
  delay(100);
  const uint8_t N = sizeof(DISPLAY_FADE_FRAMES) / sizeof(DISPLAY_FADE_FRAMES[0]);
  for (uint8_t i = 0; i < N; i++) {
    renderAnimFrame(&DISPLAY_FADE_FRAMES[i]);
  }
  delay(1000);
}
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
void loop() {
  button1.tick();
  button2.tick();

  debounceSTART();
  debounceVORTEX();

  delay(10);

  strip.show();
  blinkLEDUnified(etatArduinoLED);
  normal();

  if (digitalRead(BP_VORTEX) == LOW) {
    BP_VORTEX_STATUS = true;
  }
  if ((digitalRead(BP_UP) == LOW) && (digitalRead(BP_DOWN) == LOW)) {
    mode_test();
  }
  if (digitalRead(BP_START) == true) {
    BP_START_STATUS = true;
  }
}

void reboot() {
  // Reset propre via le watchdog (vs jump a 0 qui ne reset pas les peripheriques)
  wdt_enable(WDTO_15MS);
  while (1) {}
}

void click1() {
  veille();
}
void click2() {
  menu_up();
  buzzer_menu();
}

void longPress1() {
  reveille();
}
void longPress2() {
  reboot();
}

void doubleclick1() {
  zap();
}
void doubleclick2() {
  BP_POWER_STATUS = true;
}

const uint64_t IMAGES_POST_FIN[] PROGMEM = {
  0x0000000000000000, 0x0000000102000000, 0x0000008106000000, 0x000000c10e000000,
  0x000000e11e000000, 0x000000f13e000000, 0x000000f97e000000, 0x000000fdfe000000,
  0x000000ffff000000, 0x000000fdfe000000, 0x000000f97e000000, 0x000000f13e000000,
  0x000000e11e000000, 0x000000c10e000000, 0x0000008106000000, 0x0000000102000000
};

const uint64_t IMAGES_NORMAL[] PROGMEM = {
  0x0000000000000000, 0x0000000201000000, 0x0000000681000000, 0x0000000ec1000000,
  0x0000001ee1000000, 0x0000003ef1000000, 0x0000001ee1000000, 0x0000000ec1000000,
  0x0000001ee1000000, 0x0000003ef1000000, 0x0000007ef9000000, 0x000000fefd000000,
  0x000000ffff000000, 0x000000fefd000000, 0x0000007ef9000000, 0x0000003ef1000000,
  0x0000001ee1000000, 0x0000000ec1000000, 0x0000001ee1000000, 0x0000003ef1000000,
  0x0000001ee1000000, 0x0000000ec1000000, 0x0000000681000000, 0x0000000201000000
};

const uint64_t IMAGES_FIN[] PROGMEM = {
  0x0000000000000000, 0x0000000101000000, 0x0000008181000000, 0x0000008383000000,
  0x000000c3c3000000, 0x000000c7c7000000, 0x000000e7e7000000, 0x000000f7f7000000,
  0x000000ffff000000, 0x000000f7f7000000, 0x000000e7e7000000, 0x000000c7c7000000,
  0x000000c3c3000000, 0x0000008383000000, 0x0000008181000000, 0x0000000101000000,
  0x0000000000000000, 0x0000000101000000, 0x0000008181000000, 0x0000008383000000,
  0x000000c3c3000000, 0x000000c7c7000000, 0x000000e7e7000000, 0x000000f7f7000000,
  0x000000ffff000000, 0x000000f7f7000000, 0x000000e7e7000000, 0x000000c7c7000000,
  0x000000c3c3000000, 0x0000008383000000, 0x0000008181000000, 0x0000000101000000,
  0x0000000000000000, 0x0000000000000000, 0x0000000101000000, 0x0000008181000000,
  0x0000008383000000, 0x000000c3c3000000, 0x000000c7c7000000, 0x000000e7e7000000,
  0x000000e7cf000000, 0x000000f39f000000, 0x000000f93f000000, 0x000000fd7f000000,
  0x000000f99f000000, 0x000000f3cf000000, 0x000000e7e7000000, 0x000000cff3000000,
  0x0000009ff9000000, 0x0000003ffd000000, 0x0000009ff9000000, 0x000000cff3000000,
  0x000000e7e7000000, 0x000000f3cf000000, 0x000000f99f000000, 0x000000fd7f000000,
  0x000000f99f000000, 0x000000f3cf000000, 0x000000e7e7000000, 0x000000cff3000000,
  0x0000009ff9000000, 0x0000003ffd000000, 0x0000007ffd000000, 0x0000009ff9000000,
  0x000000cff3000000, 0x000000e7e7000000, 0x000000f3cf000000, 0x000000f99f000000,
  0x000000fd3f000000, 0x000000f97f000000, 0x000000f33f000000, 0x000000e79f000000,
  0x000000cfcf000000, 0x0000009fe7000000, 0x0000003ff3000000, 0x0000007ff9000000,
  0x0000003ffc000000, 0x0000009ff9000000, 0x000000cff3000000, 0x000000e7e7000000
};

const uint64_t IMAGES_OFF[] PROGMEM = {
  0x0000000000000000
};

Bargraphe bargraphePostFin = { IMAGES_POST_FIN, sizeof(IMAGES_POST_FIN) / 8, 0, 15 };
Bargraphe bargrapheNormal = { IMAGES_NORMAL, sizeof(IMAGES_NORMAL) / 8, 0, 20 };
Bargraphe bargrapheFin = { IMAGES_FIN, sizeof(IMAGES_FIN) / 8, 0, 15 };
Bargraphe bargrapheOff = { IMAGES_OFF, sizeof(IMAGES_OFF) / 8, 0, 0 };

void displayImage(const uint64_t image) {
  for (int row = 3; row < 5; row++) {
    byte rowData = (image >> (row * 8)) & 0xFF;
    for (int col = 0; col < 8; col++) {
      lc.setLed(1, row, col, bitRead(rowData, col));
    }
  }
}

void animateBargraphe(Bargraphe &bargraphe) {
  uint64_t img;
  memcpy_P(&img, &bargraphe.images[bargraphe.index], sizeof(uint64_t));
  displayImage(img);
  if (++bargraphe.index >= bargraphe.length) {
    bargraphe.index = 0;
  }
  delay(bargraphe.delayTime);
}

#define secondsinaday 86400
#define secondsinhour 3600
#define secondsinminute 60

void showTime() {
  unsigned long days = totalsectime / secondsinaday;
  unsigned long hours = (totalsectime % secondsinaday) / secondsinhour;
  unsigned long minutes = (totalsectime % secondsinhour) / secondsinminute;
  unsigned long seconds = totalsectime % secondsinminute;

  // Days
  lc.setDigit(1, 0, days / 100, false);
  lc.setDigit(1, 1, (days % 100) / 10, false);
  lc.setDigit(1, 2, days % 10, false);

  // Hours
  lc.setDigit(0, 0, hours / 10, false);
  lc.setDigit(0, 1, hours % 10, false);

  // Minutes
  lc.setDigit(0, 2, minutes / 10, false);
  lc.setDigit(0, 3, minutes % 10, false);

  // Seconds
  lc.setDigit(0, 4, seconds / 10, false);
  lc.setDigit(0, 5, seconds % 10, false);
}

void delayIncrement(byte rst) {
  static unsigned long last_time3 = 0;
  unsigned long time_now3 = millis();

  if (rst) {
    last_time3 = time_now3;
    return;
  }

  if (time_now3 - last_time3 >= 1000) {
    delay(100);
  } else {
    delay(150);
  }
}

void handleMenu(int menu, int increment, int digitPosition, bool isDayMenu = false) {
  button1.tick();
  button2.tick();

  ecranBlinkUnified(false, isDayMenu ? 1 : 0, digitPosition);

  if (digitalRead(BP_UP) == LOW) {
    customTone(3000, 50);

    if (isDayMenu) {
      unsigned long currentDays = totalsectime / 86400;
      currentDays++;
      totalsectime = (currentDays * 86400) + (totalsectime % 86400);
    } else {
      totalsectime += increment;
    }

    delayIncrement(false);
    showTime();
  } else {
    delayIncrement(true);
  }

  if (digitalRead(BP_DOWN) == LOW) {
    customTone(2900, 50);

    if (isDayMenu) {
      unsigned long currentDays = totalsectime / 86400;
      if (currentDays > 0) {
        currentDays--;
      }
      totalsectime = (currentDays * 86400) + (totalsectime % 86400);
    } else if (totalsectime >= (unsigned long)increment) {
      totalsectime -= increment;
    } else {
      totalsectime = 0;
    }

    delayIncrement(false);
    showTime();
  } else {
    delayIncrement(true);
  }
}

void buttonStart() {
  running = !running;
}

// Effet "scramble" rapide sur les 2 digits secondes (matrix 0, rows 4-5)
// pour donner un tick visuel a chaque incrementation/decrementation.
// ~45ms total, non bloquant pour le timing 1Hz du countdown.
void animateSecondTick() {
  for (uint8_t i = 0; i < 3; i++) {
    lc.setDigit(0, 4, random(10), false);
    lc.setDigit(0, 5, random(10), false);
    delay(15);
  }
}

// Animation idle: pulse lent des NeoPixels (effet "respiration") quand le
// timer est allume mais ni en running ni en menu. Ne touche pas la couleur
// des pixels (adafruit gere ca via le potentiometre), juste la brightness.
void idleAnimation() {
  const uint16_t period = 3000;  // 3 sec / pulsation
  uint16_t phase = millis() % period;
  uint16_t halfPeriod = period / 2;
  uint8_t brightness;
  if (phase < halfPeriod) {
    brightness = 3 + (uint8_t)((12UL * phase) / halfPeriod);   // 3 -> 15
  } else {
    brightness = 15 - (uint8_t)((12UL * (phase - halfPeriod)) / halfPeriod);  // 15 -> 3
  }
  strip.setBrightness(brightness);
  strip.show();
}

// Pulse la brightness des NeoPixels en fonction du temps restant.
// Plus le temps restant est court, plus la pulsation est rapide.
// Force aussi la couleur des pixels (rouge selon prevVal) car adafruit() ne
// refresh que si le potentiometre a change.
void pulseNeoPixel(unsigned long reste) {
  uint16_t period;
  if (reste <= 5)        period = 200;   // 5 Hz - stress final
  else if (reste <= 10)  period = 350;   // ~3 Hz - panique
  else if (reste <= 20)  period = 600;   // ~1.6 Hz - urgence
  else if (reste <= 30)  period = 900;   // ~1 Hz - warning
  else                   period = 1800;  // 0.55 Hz - calme

  unsigned long t = millis() % period;
  uint8_t brightness;
  uint16_t halfPeriod = period / 2;
  if (t < halfPeriod) {
    brightness = 5 + (uint8_t)((45UL * t) / halfPeriod);   // 5 -> 50
  } else {
    brightness = 50 - (uint8_t)((45UL * (t - halfPeriod)) / halfPeriod);  // 50 -> 5
  }
  // Reapplique les couleurs (au cas ou un autre code les a effacees)
  for (uint8_t p = 0; p < 7; p++) {
    strip.setPixelColor(p, p < (uint8_t)prevVal ? Red : Off);
  }
  strip.setBrightness(brightness);
  strip.show();
}
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

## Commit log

2024-09-15 add new stl
    [Battery_box v1.stl, Button_plate v1.stl, Crystal v1.stl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]
2024-09-17 update custom stl
    [Battery_box v6.stl, Face_plate v1.stl, Face_plate v2.stl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]
2024-09-22 fix mute mode & fix adafruit on/off in burnout mode & add auto off spleep mode
    [sliders_timer_main.ino]
2024-09-22 add some custom stl
    [Aside_parts v8.stl, BatteryBox.STL, Battery_box v1.stl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]
2024-09-26 add some pictures
    [Aside_parts v8.stl, BatteryBox.STL, Battery_box v1.stl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]
2024-10-06 update stl button plate
    [Cover_Button_plate v10.stl, Cover_Button_plate v12.stl]
2024-10-06 fix stl cover top
    [Cover_Top_face v13.stl, Cover_Top_face v14.stl]
2024-12-30 update diagram & gerber
